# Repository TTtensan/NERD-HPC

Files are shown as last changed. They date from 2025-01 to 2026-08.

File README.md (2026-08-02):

# [NERD-HPC](https://github.com/TTtensan/NERD-HPC)

## アップデート方法
1. 本体とPCをUSBで接続する。
2. BOOTを押しながらPowerをONにする。もしくはPowerをONにした後にBOOTを押しながらRESETボタンを押す。
3. パソコンにRPI-RP2として認識されるのでsoftware/build/src/NERD_HPC.uf2をドラッグ&ドロップする。

## ファームウェアのビルド方法
どちらの方法でも、ビルド成果物は`software/build/src/NERD_HPC.uf2`に出力されます。

### コマンドラインでビルドする場合
```
(Ubuntu Desktop 24.04.1 LTS)
sudo apt install cmake python3 build-essential gcc-arm-none-eabi libnewlib-arm-none-eabi libstdc++-arm-none-eabi-newlib
```
```
git clone --recursive https://github.com/TTtensan/NERD-HPC.git
cd NERD-HPC/software
cmake -B build
cd build
make
```
この方法では、リポジトリに同梱されている`software/libraries/pico-sdk`(サブモジュール)を使ってビルドします。`--recursive`を忘れずに。

### VS Codeでビルドする場合
[Raspberry Pi Pico拡張機能](https://marketplace.visualstudio.com/items?itemName=raspberry-pi.raspberry-pi-pico)を使います。

1. リポジトリをクローンし、`software`フォルダをVS Codeで開く。
2. 推奨拡張機能のインストールを促されるので、インストールする(`.vscode/extensions.json`に定義しています)。
3. Pico拡張機能が必要なツールチェーンを`~/.pico-sdk`以下に自動でダウンロードします。使用するバージョンは`software/CMakeLists.txt`の先頭で指定しています(Pico SDK 2.2.0 / GCC 14_2_Rel1 / picotool 2.2.0-a4)。
4. サイドバーのPicoアイコンから`Compile Project`を実行する。

`.vscode`以下の設定はリポジトリで共有しています。パスはすべて`${userHome}`などの変数で書いてあるため、Windows・macOS・Linuxのいずれでもそのまま動作します。

なお、この方法ではコマンドラインの場合と違い、同梱のサブモジュールではなく`~/.pico-sdk`にダウンロードされたSDKが使われます。

## その他リンク
- 本家豊四季タイニーBASIC(Arduino版)。素晴らしいプログラムをオープンソースライセンスで公開いただいていること、大変感謝しています。製作者様に本オープンソースプロジェクトについて連絡済みです。GPLのバージョンはGPLv3とのこと。<br>[ttbasic\_arduino](https://github.com/vintagechips/ttbasic_arduino)

- CHR、2進数、16進数の処理はこちらを参考にしました。大変参考になりました。<br>[ttbasic\_arduino\_stm32](https://github.com/Tamakichi/ttbasic_arduino_stm32)

- フォントデータ。こちらをベースに一部変更しています。これによって少ないデータでフォントデータを実装することができました。ありがとうございます。<br>[ＡＱＭ１２４８Ａ グラフィックＬＣＤ (for Arduino)](https://hatakekara.com/aqm1248a/)

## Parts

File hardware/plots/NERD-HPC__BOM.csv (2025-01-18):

Reference | Value | Datasheet | Footprint | Qty | DNP
BT1,BT2,BT3,BT4 | Battery_Cell | https://akizukidenshi.com/catalog/g/g102670/ | Battery:BatteryHolder_Keystone_2466_1xAAA | 4
C1,C2,C3,C5,C7,C8,C9,C10,C11,C12,C14,C17,C19,C20,C31 | 0.1uF | https://akizukidenshi.com/catalog/g/g113374/ | Capacitor_SMD:C_0603_1608Metric | 15
C4,C15,C21,C22,C23,C24,C25,C26,C27,C28,C29 | 1uF | https://akizukidenshi.com/catalog/g/g114526/ | Capacitor_SMD:C_0603_1608Metric | 11
C6 | 10uF | https://akizukidenshi.com/catalog/g/g113161/ | Capacitor_SMD:C_0603_1608Metric | 1
C13 | 0.47uF | https://akizukidenshi.com/catalog/g/g114554/ | Capacitor_SMD:C_0603_1608Metric | 1
C16,C18 | 2.2uF | https://akizukidenshi.com/catalog/g/g116077/ | Capacitor_SMD:C_0603_1608Metric | 2
C30 | 100uF | https://akizukidenshi.com/catalog/g/g115633/ | Capacitor_SMD:C_1206_3216Metric | 1
D1,D2,D3,D5,D6,D7,D8,D9,D10,D11,D12,D13,D14 | D_Schottky | https://akizukidenshi.com/catalog/g/g111231/ | LocalFootprintLibrary:CUS01 | 13
D4 | LED | https://akizukidenshi.com/catalog/g/g104313/ | LED_THT:LED_D3.0mm | 1
J1 | USB_C_Receptacle | https://akizukidenshi.com/catalog/g/g114356/ | Connector_USB:USB_C_Receptacle_XKB_U262-16XN-4BVC11 | 1
J2 | Micro_SD_Card_Det_Hirose_DM3AT | https://akizukidenshi.com/catalog/g/g102395/ | Connector_Card:microSD_HC_Hirose_DM3AT-SF-PEJM5 | 1
J3,J4 | Conn_01x06_Socket | https://akizukidenshi.com/catalog/g/g103784/ | Connector_PinSocket_2.54mm:PinSocket_1x06_P2.54mm_Vertical | 2
LS1 | Speaker | https://akizukidenshi.com/catalog/g/g106707/ | LocalFootprintLibrary:UM1515IA085008 | 1
Q1 | Q_PMOS_GSD | https://akizukidenshi.com/catalog/g/g102553/ | Package_TO_SOT_SMD:SOT-23 | 1
Q2 | Q_NMOS_GSD | https://akizukidenshi.com/catalog/g/g106049/ | Package_TO_SOT_SMD:SOT-23 | 1
R1,R6,R7,R8,R10,R11,R12,R13 | 10k | https://akizukidenshi.com/catalog/g/g115029/ | Resistor_SMD:R_0603_1608Metric | 8
R2,R3,R9 | 27 | free | Resistor_SMD:R_0603_1608Metric | 3
R4,R5,R14,R15,R16,R17 | 5.1k | https://www.sengoku.co.jp/mod/sgk_cart/detail.php?code=EEHD-57GS | Resistor_SMD:R_0603_1608Metric | 6
R18 | 200 | free | Resistor_SMD:R_0603_1608Metric | 1
RV1,RV2 | R_Potentiometer | https://akizukidenshi.com/catalog/g/g106099/ | LocalFootprintLibrary:3386K-EY5-101TR | 2
SW1,SW2,SW6,SW7,SW8,SW9,SW10,SW11,SW12,SW13,SW14,SW15,SW16,SW17,SW18,SW19,SW20,SW21,SW22,SW23,SW24,SW25,SW26,SW27,SW28,SW29,SW30,SW31,SW32,SW33,SW34,SW35,SW36,SW37,SW38,SW39,SW40,SW41,SW42,SW43,SW44,SW45,SW46,SW47,SW48,SW49,SW50,SW51,SW52,SW53,SW54,SW55,SW56,SW57,SW58,SW59,SW60,SW61,SW62,SW63,SW64,SW65,SW66,SW67,SW68,SW69,SW70 | SW_Push | https://akizukidenshi.com/catalog/g/g103648/ | Button_Switch_THT:SW_PUSH_6mm | 67
SW3,SW4,SW5 | SW_SPDT_312 | https://akizukidenshi.com/catalog/g/g112723/ | LocalFootprintLibrary:SS-12D00-G5 | 3
U1 | RP2040 | https://akizukidenshi.com/catalog/g/g117056/ | Package_DFN_QFN:QFN-56-1EP_7x7mm_P0.4mm_EP3.2x3.2mm | 1
U2 | NJM2845DL1-33 | https://akizukidenshi.com/catalog/g/g111299/ | Package_TO_SOT_SMD:TO-252-3_TabPin2 | 1
U3 | W25Q32JVSS | https://akizukidenshi.com/catalog/g/g117346/ | Package_SON:Winbond_USON-8-1EP_3x2mm_P0.5mm_EP0.2x1.6mm | 1
U4 | MCP23017_SP | https://akizukidenshi.com/catalog/g/g109486/ | Package_DIP:DIP-28_W7.62mm | 1
U5 | AQM1248A | https://akizukidenshi.com/catalog/g/g110048/ | LocalFootprintLibrary:AQM1248A | 1
U6 | OSRB38C9AA | https://akizukidenshi.com/catalog/g/g104659/ | LocalFootprintLibrary:OSRB38C9AA | 1
X1 | SIT2001B | https://akizukidenshi.com/catalog/g/g111093/ | Package_TO_SOT_SMD:SOT-23-5 | 1

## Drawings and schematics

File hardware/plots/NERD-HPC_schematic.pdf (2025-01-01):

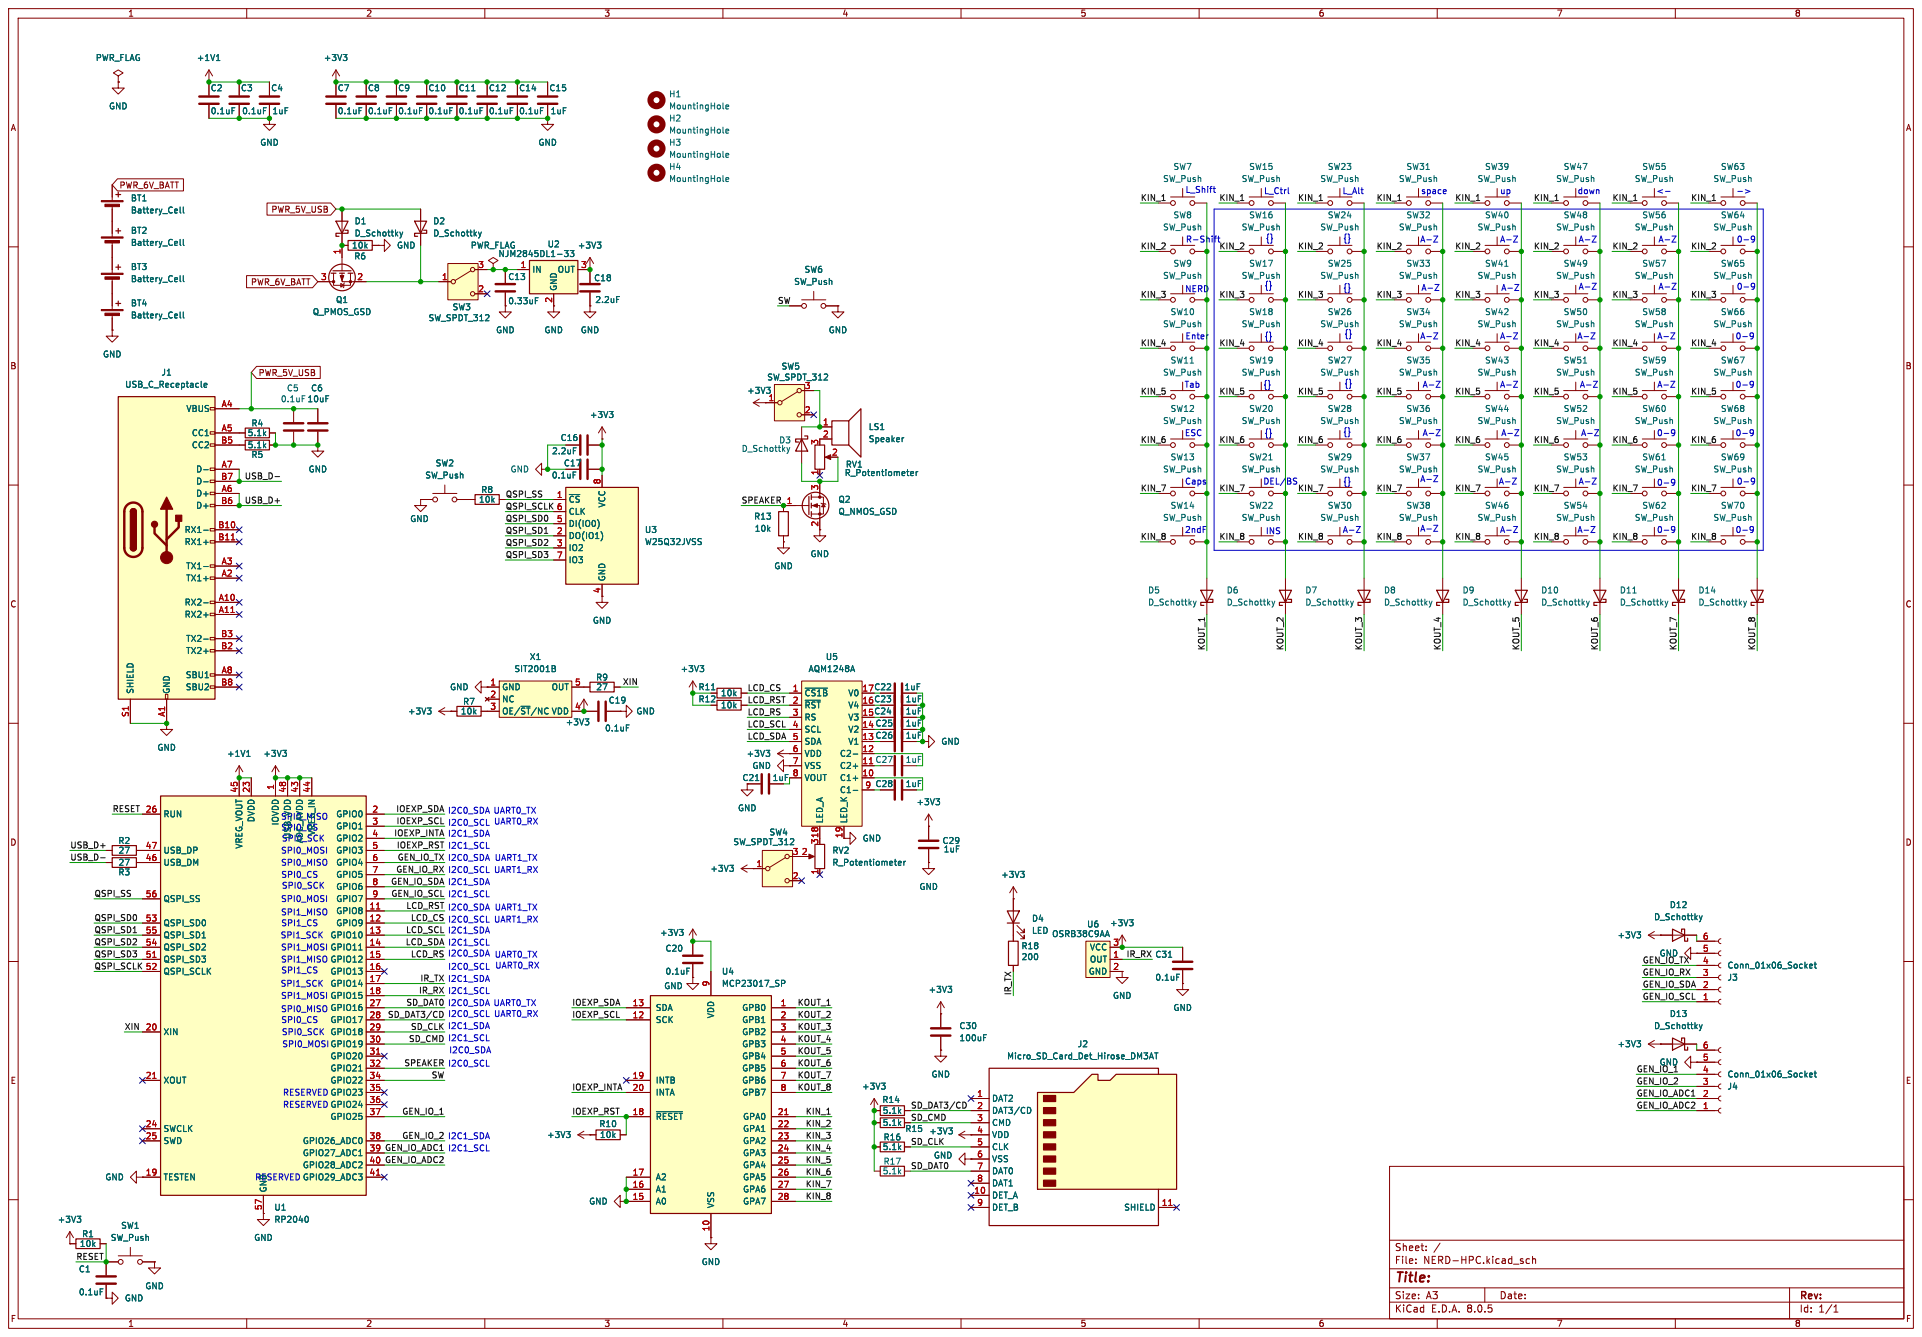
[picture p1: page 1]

H2 MountingHole H4 MountingHole H1 MountingHole H3 MountingHole C11

1 GPIO8 11 GPIO9 12 GPIO10 13 GPIO11 14 GPIO12 15 GPIO13 16 GPIO14 17 GPIO15 18 TESTEN 19 GPIO0 2 XIN 20 XOUT 21 DVDD 23 SWCLK 24 SWD 25 RUN 26 GPIO16 27 GPIO17 28 GPIO18 29 GPIO1 3 GPIO19 30 GPIO20 31 GPIO21 32 GPIO22 34 GPIO23 35 GPIO24 36 GPIO25 37 GPIO26_ADC0 38 GPIO27_ADC1 39 GPIO2 4 GPIO28_ADC2 40 GPIO29_ADC3 41 ADC_AVDD 43 VREG_IN 44 VREG_VOUT 45 USB_DM 46 USB_DP 47 USB_VDD 48 GPIO3 5 QSPI_SD3 51 QSPI_SCLK 52 QSPI_SD0 53 QSPI_SD2 54 QSPI_SD1 55 QSPI_SS 56 GND 57 GPIO4 6 GPIO5 7 GPIO6 8 GPIO7 9 +3V3 U4 MCP23017_SP GPB0 1 VSS 10 SCK 12 SDA 13 A0 15 A1 16 A2 17 ~{RESET} 18

1 GPIO8 11 GPIO9 12 GPIO10 13 GPIO11 14 GPIO12 15 GPIO13 16 GPIO14 17 GPIO15 18 TESTEN 19 GPIO0 2 XIN 20 XOUT 21 DVDD 23 SWCLK 24 SWD 25 RUN 26 GPIO16 27 GPIO17 28 GPIO18 29 GPIO1 3 GPIO19 30 GPIO20 31 GPIO21 32 GPIO22 34 GPIO23 35 GPIO24 36 GPIO25 37 GPIO26_ADC0 38 GPIO27_ADC1 39 GPIO2 4 GPIO28_ADC2 40 GPIO29_ADC3 41 ADC_AVDD 43 VREG_IN 44 VREG_VOUT 45 USB_DM 46 USB_DP 47 USB_VDD 48 GPIO3 5 QSPI_SD3 51 QSPI_SCLK 52 QSPI_SD0 53 QSPI_SD2 54 QSPI_SD1 55 QSPI_SS 56 GND 57 GPIO4 6 GPIO5 7 GPIO6 8 GPIO7 9 U1 RP2040

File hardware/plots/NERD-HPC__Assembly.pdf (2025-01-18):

1 | 2 | 3 | 4 | 5 | 6

A

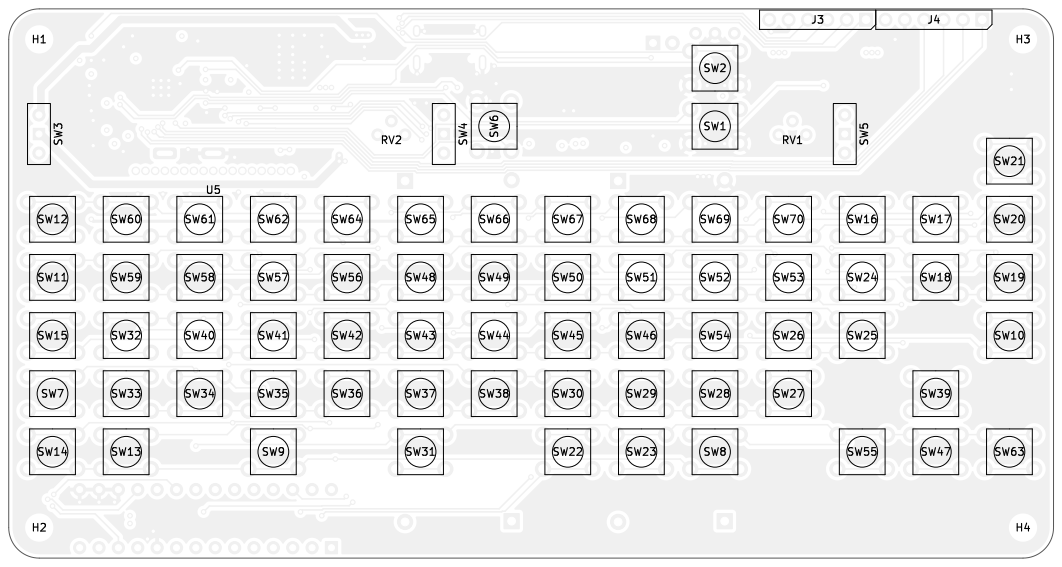
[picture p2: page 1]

1 | 2 | 3 | 4 | 5 | 6

A

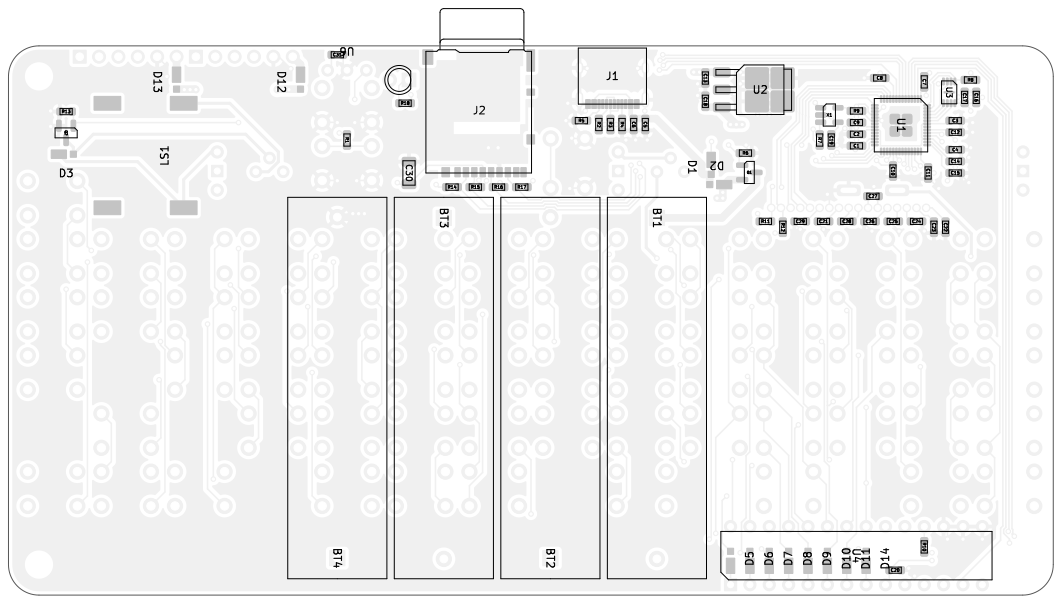
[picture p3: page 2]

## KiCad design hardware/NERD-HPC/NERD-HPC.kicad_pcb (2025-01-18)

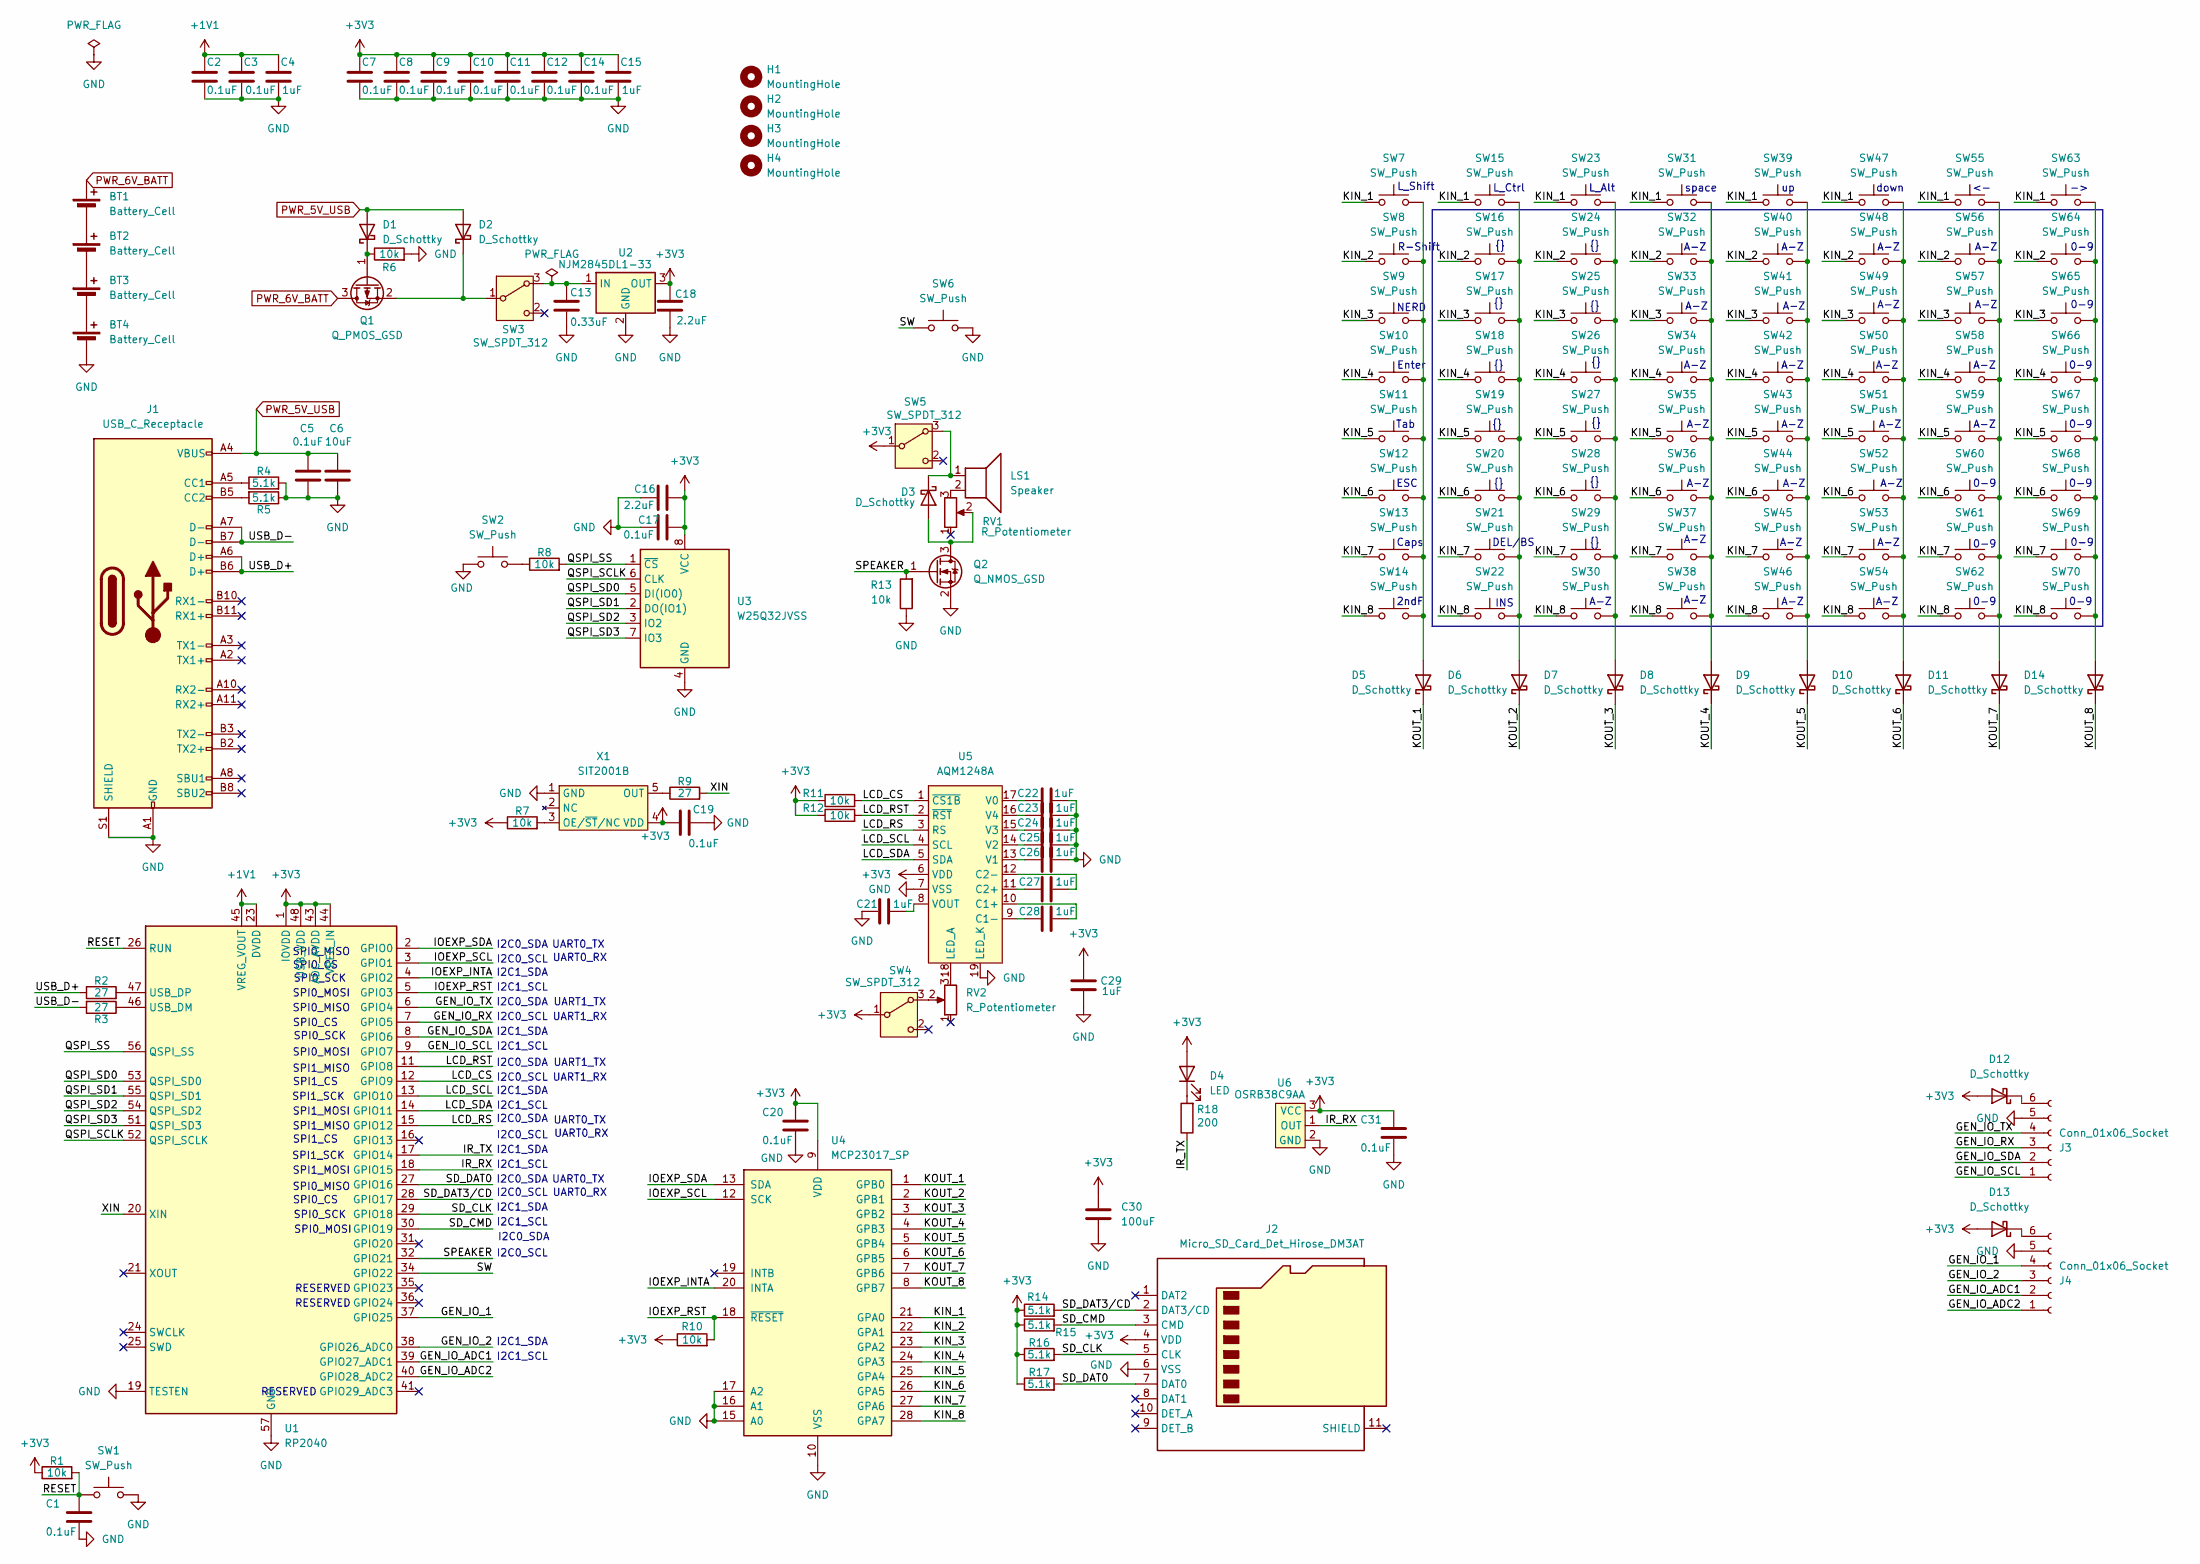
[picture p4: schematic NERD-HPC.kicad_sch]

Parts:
BT1, BT2, BT3, BT4: Battery_Cell; BatteryHolder_Keystone_2466_1xAAA
C1, C2, C3, C5, C7, C8, C9, C10, C11, C12, C14, C17, C19, C20, C31: 0.1uF; C_0603_1608Metric
C4, C15, C21, C22, C23, C24, C25, C26, C27, C28, C29: 1uF; C_0603_1608Metric
C6: 10uF; C_0603_1608Metric
C13: 0.33uF; C_0603_1608Metric
C16, C18: 2.2uF; C_0603_1608Metric
C30: 100uF; C_1206_3216Metric
D1, D2, D3, D5, D6, D7, D8, D9, D10, D11, D12, D13, D14: D_Schottky; CUS01
D4: LED; LED_D3.0mm
H1, H2, H3, H4: MountingHole; MountingHole_3.2mm_M3
J1: USB_C_Receptacle; USB_C_Receptacle_XKB_U262-16XN-4BVC11
J2: Micro_SD_Card_Det_Hirose_DM3AT; microSD_HC_Hirose_DM3AT-SF-PEJM5
J3, J4: Conn_01x06_Socket; PinSocket_1x06_P2.54mm_Vertical
LS1: Speaker; UM1515IA085008
Q1: Q_PMOS_GSD; SOT-23
Q2: Q_NMOS_GSD; SOT-23
R1, R6, R7, R8, R10, R11, R12, R13: 10k; R_0603_1608Metric
R2, R3, R9: 27; R_0603_1608Metric
R4, R5, R14, R15, R16, R17: 5.1k; R_0603_1608Metric
R18: 200; R_0603_1608Metric
RV1, RV2: R_Potentiometer; 3386K-EY5-101TR
SW1, SW2, SW6, SW7, SW8, SW9, SW10, SW11, SW12, SW13, SW14, SW15, SW16, SW17, SW18, SW19, SW20, SW21, SW22, SW23, SW24, SW25, SW26, SW27, SW28, SW29, SW30, SW31, SW32, SW33, SW34, SW35, SW36, SW37, SW38, SW39, SW40, SW41, SW42, SW43, SW44, SW45, SW46, SW47, SW48, SW49, SW50, SW51, SW52, SW53, SW54, SW55, SW56, SW57, SW58, SW59, SW60, SW61, SW62, SW63, SW64, SW65, SW66, SW67, SW68, SW69, SW70: SW_Push; SW_PUSH_6mm
SW3, SW4, SW5: SW_SPDT_312; SS-12D00-G5
U1: RP2040; QFN-56-1EP_7x7mm_P0.4mm_EP3.2x3.2mm
U2: NJM2845DL1-33; TO-252-3_TabPin2
U3: W25Q32JVSS; Winbond_USON-8-1EP_3x2mm_P0.5mm_EP0.2x1.6mm
U4: MCP23017_SP; DIP-28_W7.62mm
U5: AQM1248A
U6: OSRB38C9AA
X1: SIT2001B; SOT-23-5

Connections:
+1V1: C2.1, C3.1, C4.1, U1.23 (DVDD), U1.45 (VREG_VOUT), U1.50 (DVDD)
+3V3: C7.1, C8.1, C9.1, C10.1, C11.1, C12.1, C14.1, C15.1, C16.2, C17.1, C18.1, C19.2, C20.1, C29.1, C30.1, C31.1, D4.2 (A), D12.2 (A), D13.2 (A), J2.4 (VDD), R1.1, R7.1, R10.1, R11.1, R12.1, R14.1, R15.1, R16.1, R17.1, SW4.1 (B), SW5.1 (B), U1.1 (IOVDD), U1.10 (IOVDD), U1.22 (IOVDD), U1.33 (IOVDD), U1.42 (IOVDD), U1.43 (ADC_AVDD), U1.44 (VREG_IN), U1.48 (USB_VDD), U1.49 (IOVDD), U2.3 (OUT), U3.8 (VCC), U4.9 (VDD), U5.6 (VDD), U6.3 (VCC), X1.4 (VDD)
/GEN_IO_1: J4.4, U1.37 (GPIO25)
/GEN_IO_2: J4.3, U1.38 (GPIO26_ADC0)
/GEN_IO_ADC1: J4.2, U1.39 (GPIO27_ADC1)
/GEN_IO_ADC2: J4.1, U1.40 (GPIO28_ADC2)
/GEN_IO_RX: J3.3, U1.7 (GPIO5)
/GEN_IO_SCL: J3.1, U1.9 (GPIO7)
/GEN_IO_SDA: J3.2, U1.8 (GPIO6)
/GEN_IO_TX: J3.4, U1.6 (GPIO4)
/IOEXP_INTA: U1.4 (GPIO2), U4.20 (INTA)
/IOEXP_RST: R10.2, U1.5 (GPIO3), U4.18 (~RESET)
/IOEXP_SCL: U1.3 (GPIO1), U4.12 (SCK)
/IOEXP_SDA: U1.2 (GPIO0), U4.13 (SDA)
/IR_RX: U1.18 (GPIO15), U6.1 (OUT)
/IR_TX: R18.1, U1.17 (GPIO14)
/KIN_1: SW7.1, SW15.1, SW23.1, SW31.1, SW39.1, SW47.1, SW55.1, SW63.1, U4.21 (GPA0)
/KIN_2: SW8.1, SW16.1, SW24.1, SW32.1, SW40.1, SW48.1, SW56.1, SW64.1, U4.22 (GPA1)
/KIN_3: SW9.1, SW17.1, SW25.1, SW33.1, SW41.1, SW49.1, SW57.1, SW65.1, U4.23 (GPA2)
/KIN_4: SW10.1, SW18.1, SW26.1, SW34.1, SW42.1, SW50.1, SW58.1, SW66.1, U4.24 (GPA3)
/KIN_5: SW11.1, SW19.1, SW27.1, SW35.1, SW43.1, SW51.1, SW59.1, SW67.1, U4.25 (GPA4)
/KIN_6: SW12.1, SW20.1, SW28.1, SW36.1, SW44.1, SW52.1, SW60.1, SW68.1, U4.26 (GPA5)
/KIN_7: SW13.1, SW21.1, SW29.1, SW37.1, SW45.1, SW53.1, SW61.1, SW69.1, U4.27 (GPA6)
/KIN_8: SW14.1, SW22.1, SW30.1, SW38.1, SW46.1, SW54.1, SW62.1, SW70.1, U4.28 (GPA7)
/KOUT_1: D5.1 (K), U4.1 (GPB0)
/KOUT_2: D6.1 (K), U4.2 (GPB1)
/KOUT_3: D7.1 (K), U4.3 (GPB2)
/KOUT_4: D8.1 (K), U4.4 (GPB3)
/KOUT_5: D9.1 (K), U4.5 (GPB4)
/KOUT_6: D10.1 (K), U4.6 (GPB5)
/KOUT_7: D11.1 (K), U4.7 (GPB6)
/KOUT_8: D14.1 (K), U4.8 (GPB7)
/LCD_CS: R11.2, U1.12 (GPIO9), U5.1 (~CS1B)
/LCD_RS: U1.15 (GPIO12), U5.3 (RS)
/LCD_RST: R12.2, U1.11 (GPIO8), U5.2 (~RST)
/LCD_SCL: U1.13 (GPIO10), U5.4 (SCL)
/LCD_SDA: U1.14 (GPIO11), U5.5 (SDA)
/QSPI_SCLK: U1.52 (QSPI_SCLK), U3.6 (CLK)
/QSPI_SD0: U1.53 (QSPI_SD0), U3.5 (DI(IO0))
/QSPI_SD1: U1.55 (QSPI_SD1), U3.2 (DO(IO1))
/QSPI_SD2: U1.54 (QSPI_SD2), U3.3 (IO2)
/QSPI_SD3: U1.51 (QSPI_SD3), U3.7 (IO3)
/QSPI_SS: R8.2, U1.56 (QSPI_SS), U3.1 (~CS)
/RESET: C1.1, R1.2, SW1.1, U1.26 (RUN)
/SD_CLK: J2.5 (CLK), R16.2, U1.29 (GPIO18)
/SD_CMD: J2.3 (CMD), R15.2, U1.30 (GPIO19)
/SD_DAT0: J2.7 (DAT0), R17.2, U1.27 (GPIO16)
/SD_DAT3/CD: J2.2 (DAT3/CD), R14.2, U1.28 (GPIO17)
/SPEAKER: Q2.1 (G), R13.2, U1.32 (GPIO21)
/SW: SW6.1, U1.34 (GPIO22)
/USB_D+: J1.A6 (D+), J1.B6 (D+), R2.1
/USB_D-: J1.A7 (D-), J1.B7 (D-), R3.2
/XIN: R9.2, U1.20 (XIN)
GND: BT4.2 (-), C1.2, C2.2, C3.2, C4.2, C5.2, C6.2, C7.2, C8.2, C9.2, C10.2, C11.2, C12.2, C13.2, C14.2, C15.2, C16.1, C17.2, C18.2, C19.1, C20.2, C21.1, C22.2, C23.2, C24.2, C25.2, C26.2, C29.2, C30.2, C31.2, J1.A1 (GND), J1.A12 (GND), J1.B1 (GND), J1.B12 (GND), J1.S1 (SHIELD), J2.6 (VSS), J3.5, J4.5, Q2.2 (S), R4.2, R5.1, R6.2, R13.1, SW1.2, SW2.1, SW6.2, U1.19 (TESTEN), U1.57 (GND), U2.2 (GND), U3.4 (GND), U4.10 (VSS), U4.15 (A0), U4.16 (A1), U4.17 (A2), U5.7 (VSS), U5.19 (LED_K), U6.2 (GND), X1.1 (GND)
unnamed: BT1.2 (-), BT2.1 (+)
unnamed: BT2.2 (-), BT3.1 (+)
unnamed: BT3.2 (-), BT4.1 (+)
unnamed: D1.1 (K), Q1.1 (G), R6.1
unnamed: D2.1 (K), Q1.2 (S), SW3.1 (B)
unnamed: D3.2 (A), Q2.3 (D), RV1.2
unnamed: D3.1 (K), LS1.1, SW5.3 (A)
unnamed: D4.1 (K), R18.2
unnamed: D5.2 (A), SW7.2, SW8.2, SW9.2, SW10.2, SW11.2, SW12.2, SW13.2, SW14.2
unnamed: D6.2 (A), SW15.2, SW16.2, SW17.2, SW18.2, SW19.2, SW20.2, SW21.2, SW22.2
unnamed: D7.2 (A), SW23.2, SW24.2, SW25.2, SW26.2, SW27.2, SW28.2, SW29.2, SW30.2
unnamed: D8.2 (A), SW31.2, SW32.2, SW33.2, SW34.2, SW35.2, SW36.2, SW37.2, SW38.2
unnamed: D9.2 (A), SW39.2, SW40.2, SW41.2, SW42.2, SW43.2, SW44.2, SW45.2, SW46.2
unnamed: D10.2 (A), SW47.2, SW48.2, SW49.2, SW50.2, SW51.2, SW52.2, SW53.2, SW54.2
unnamed: D11.2 (A), SW55.2, SW56.2, SW57.2, SW58.2, SW59.2, SW60.2, SW61.2, SW62.2
unnamed: D12.1 (K), J3.6
unnamed: D13.1 (K), J4.6
unnamed: D14.2 (A), SW63.2, SW64.2, SW65.2, SW66.2, SW67.2, SW68.2, SW69.2, SW70.2
unnamed: J1.A5 (CC1), R4.1
unnamed: J1.B5 (CC2), R5.2
unnamed: LS1.2, RV1.3
unnamed: R8.1, SW2.2
unnamed: C13.1, SW3.3 (A), U2.1 (IN)
unnamed: RV2.2, SW4.3 (A)
unnamed: R3.1, U1.46 (USB_DM)
unnamed: R2.2, U1.47 (USB_DP)
unnamed: C28.2, U5.10 (C1+)
unnamed: C28.1, U5.9 (C1-)
unnamed: C27.1, U5.11 (C2+)
unnamed: C27.2, U5.12 (C2-)
unnamed: RV2.3, U5.18 (LED_A)
unnamed: C22.1, U5.17 (V0)
unnamed: C26.1, U5.13 (V1)
unnamed: C25.1, U5.14 (V2)
unnamed: C24.1, U5.15 (V3)
unnamed: C23.1, U5.16 (V4)
unnamed: C21.2, U5.8 (VOUT)
unnamed: R7.2, X1.3 (OE/~ST/NC)
unnamed: R9.1, X1.5 (OUT)
PWR_5V_USB: C5.1, C6.1, D1.2 (A), D2.2 (A), J1.A4 (VBUS), J1.A9 (VBUS), J1.B4 (VBUS), J1.B9 (VBUS)
PWR_6V_BATT: BT1.1 (+), Q1.3 (D)

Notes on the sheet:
A-Z
I2C1_SDA
I2C0_SDA
ESC
SPI1_MOSI
0-9
UART0_RX
2ndF
Tab
SPI0_SCK
I2C1_SCL
I2C0_SCL
RESERVED
DEL/BS
SPI0_CS
Caps
SPI0_MISO
SPI1_CS
UART1_RX
Enter
SPI1_SCK
R-Shift
down
UART1_TX
SPI0_MOSI
SPI1_MISO
L_Ctrl
UART0_TX
NERD
L_Alt
L_Shift
INS
space

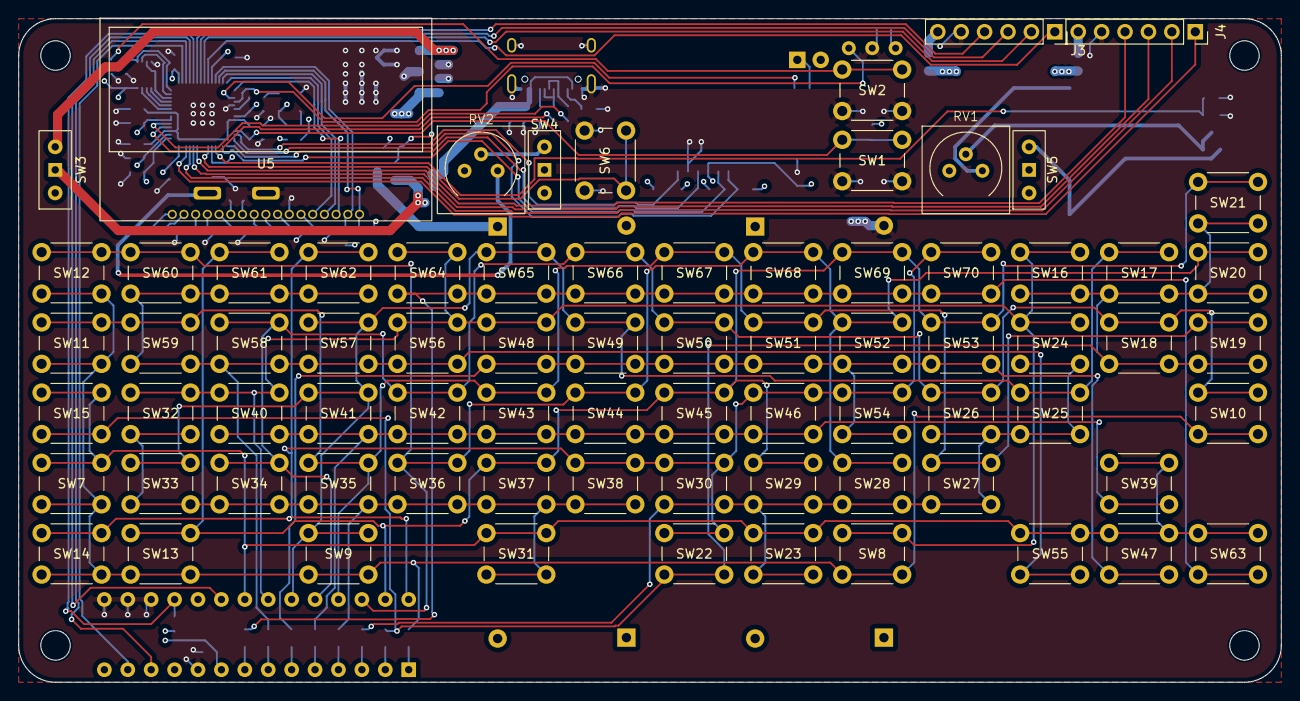
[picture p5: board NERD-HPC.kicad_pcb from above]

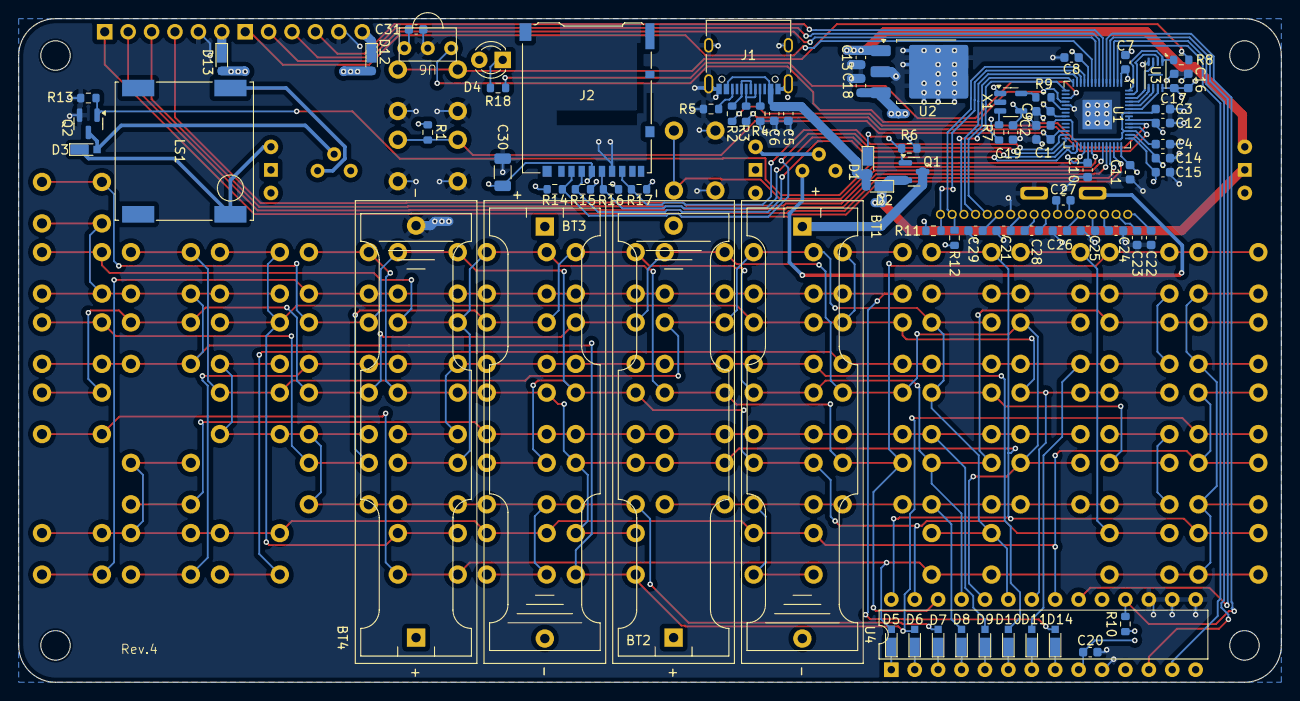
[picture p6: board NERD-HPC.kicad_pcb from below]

Board: 4 copper layers, 137.0 x 72.0 mm, 157 parts (78 on the bottom side), 95 nets.

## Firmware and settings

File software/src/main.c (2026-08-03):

#include <stdio.h>
#include "stdlib.h"
#include "pico/stdlib.h"
#include "pico/multicore.h"
#include "hardware/clocks.h"
#include "font.h"
#include "pin.h"
#include "lcd.h"
#include "speaker.h"
#include "sd.hpp"
#include "com_func.h"
#include "draw.h"
#include "io.h"
#include "ioexp.h"
#include "mcore.h"
#include "tusb.h"
#include "usb_descriptors.h"
#include "usb.h"
#include "basic.hpp"

void core1_entry() {
    while(true) {
        tud_task();
        usb_send_keycode_task();
        lcd_task(); // 画面転送。core0のBASICを止めないようこちらで回す
    }
}

int main() {

    // RP2040の水晶は12MHzで、sys_clkはそこからPLLで作られている。
    // 既定の125MHzはPLLの分周比で決まっているだけなので、
    // 基板に手を入れずにここで引き上げられる。
    // BASICの実行速度はほぼこの比で効く。
    // spi_init()/i2c_init()/PWMはclk_periから分周比を計算するので、
    // 必ずpin_init()より前に呼ぶこと
    set_sys_clock_khz(250000, true);

    stdio_init_all();
    tusb_init();

    printf("Hello, I'm NERD BOY\n");

    srand(get_seed());
    font_init();
    pin_init();
    io_init();
    ioexp_init();
    lcd_init();
    speaker_init();
    sd_init();
    mcore_init();

    multicore_launch_core1(core1_entry);

    while (true) {
        basic();
    }

}

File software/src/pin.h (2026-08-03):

#ifndef PIN_H_
#define PIN_H_

#include "hardware/i2c.h"

#define PIN_IOEXP_SDA 0
#define PIN_IOEXP_SCL 1
#define PIN_IOEXP_INTA 2
#define PIN_IOEXP_RST 3

#define PIN_GEN_IO_TX 4
#define PIN_GEN_IO_RX 5
#define PIN_GEN_IO_SDA 6
#define PIN_GEN_IO_SCL 7

#define PIN_LCD_RST 8
#define PIN_LCD_CS 9
#define PIN_LCD_SCL 10
#define PIN_LCD_SDA 11
#define PIN_LCD_RS 12

#define PIN_IR_TX 14
#define PIN_IR_RX 15

#define PIN_SD_DAT0 16
#define PIN_SD_DAT3 17
#define PIN_SD_CLK 18
#define PIN_SD_CMD 19

#define PIN_SPEAKER 21
#define PIN_SW 22

#define PIN_GEN_IO_1 25
#define PIN_GEN_IO_2 26
#define PIN_GEN_IO_3 27
#define PIN_GEN_IO_4 28

#define UART_ID_GENIO uart1
#define I2C_ID_GENIO i2c1

// 1MHz(Fast-mode Plus)は外付けプルアップが1kΩ級でないと成立しない。
// 1MHzではIOピンに指で触れただけでバスが完全無応答になり、
// MCP23017のレジスタが化けたり、キー入力が2秒ほど止まったりしていた。
// 400kHzに落とすと再現しなくなったので、こちらを採用する。
// プルアップ抵抗を1kΩ級に見直せば1MHzへ戻せる
#define I2C0_BAUDRATE 400000

void pin_init();

#endif

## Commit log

2025-01-01 add hardware file
    [NERD-HPC-B_Cu.gbl, NERD-HPC-B_Mask.gbs, NERD-HPC-B_Paste.gbp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]
2025-01-01 update bom
    [NERD-HPC.kicad_sch, NERD-HPC_CASE_B.kicad_sch, NERD-HPC_CASE_F.kicad_sch]
2025-01-01 add pico sdk
2025-01-01 use libraries/pico-sdk
2025-01-13 include dev_hid_composite sample
2025-01-13 access current_keycode
2025-01-14 fix keycode and increase list size
    [basic.cpp, ioexp.c]
2025-01-14 add keycode and fix keycode
    [ioexp.c]
2025-01-18 initial reset lcd and ioexpander
    [basic.cpp, ioexp.c, lcd.c]
2025-01-18 NERD HPC pcb Rev.4
    [NERD-HPC-B_Cu.gbl, NERD-HPC-B_Mask.gbs, NERD-HPC-B_Paste.gbp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]
2025-01-18 NERD HPC CASE F pcb Rev.4
    [NERD-HPC_CASE_F-B_Cu.gbl, NERD-HPC_CASE_F-B_Mask.gbs, NERD-HPC_CASE_F-B_Paste.gbp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]
2025-01-18 add assembly pdf
2025-01-18 add BOM file
    [NERD-HPC__BOM.csv]
2025-01-18 move plot file
    [NERD-HPC__BOM.csv]
2025-01-23 change pico sdk v1.4.0 to v2.1.0
2025-01-23 build with pico-sdk v2.1.0
2025-02-11 add GEN IO uart
2025-06-04 add i2c function
2025-06-16 fix GCLS cursor position and IOUR IOIR
    [basic.cpp, lcd.c]
2025-07-26 fix hex bin display and save
    [basic.cpp]
2025-09-22 change timer irq to pin irq
2025-09-26 change to timer interrupt and add i2c recovery process
2025-10-02 disable i2c recovery process
2026-07-21 fix: GTRI塗りつぶしで頂点位置がずれるバグを修正
    走査線塗りつぶしのx座標を(int16_t)キャストで切り捨てていたため、
    Bresenham線描画(輪郭)の丸めと不一致となり辺が最大1pxずれていた。
    lroundfで四捨五入するよう変更し、fill=0/1で頂点位置が一致するようにした。
    [lcd.c]
2026-07-21 build: GTRI塗りつぶし修正を反映したファームウェアを再ビルド
2026-07-21 Fix vertex shift in lcd_triangle fill
    The scanline fill accumulated the long-edge x (sx) across both the
    upper and lower half loops. Because sx was advanced once more after the
    last upper-half row and both loops drew the shared y1 scanline, the long
    edge was sampled one row too far in the lower half, shifting vertices by
    one pixel (e.g. two adjacent GTRI triangles left a stray pixel outside
    the intended rectangle).
    Recompute each edge x directly from the vertices per scanline instead of
    accumulating. This also removes the dx12/dx23 divisions that produced
    division-by-zero (+/-inf) on flat top/bottom edges.
    [lcd.c]
2026-08-02 ビルドフォルダを_buildからbuildへ移行し、VS Codeでのビルドに対応
    VS CodeのRaspberry Pi Pico拡張機能が生成するビルドフォルダ名に合わせて
    _buildをbuildにリネームした。追跡対象のNERD_HPC.uf2の場所と.gitignoreの
    除外設定、READMEの記載を合わせて更新している。
    またPico拡張機能が生成した設定一式を追加した。.vscode以下のパスはすべて
    ${userHome}などの変数で書かれているため、Windows・macOS・Linuxのいずれでも
    そのまま動作する。READMEにはコマンドラインとVS Codeの両方の手順を記載した。
2026-08-02 バージョンを1.13.3に更新
    STR_VERSIONを1.13.2から1.13.3に変更し、ビルド済みのNERD_HPC.uf2を更新した。
2026-08-02 gitignoreのビルド成果物の指定をsoftware/.gitignoreに一本化
    software/.gitignoreのbuildがディレクトリごと除外していたため、ルート側の
    !software/build/srcの例外が効かず、NERD_HPC.uf2をgit addできなくなっていた。
    Gitはディレクトリごと除外されたパスの中身を再包含できないため、build/*に
    変更した上で例外指定を書き直した。
    あわせてルート側の重複していた指定を削除し、software配下のビルド成果物の
    管理をsoftware/.gitignoreに集約した。
2026-08-02 fix: IO Expanderのキー入力でフリーズするバグを修正
    キースキャンをrepeating_timerのコールバック(割り込みコンテキスト)から
    実行していたが、1回のスキャンでI2Cを16回叩くため、バスが不調になると
    割り込みの中でCPUを数百ms占有して端末全体が固まっていた。
    割り込みを廃止し、メインループから呼ぶioexp_task()方式に変更。
    またIOピンに外部から触れると復帰不能になる問題が2経路あったため、
    自動復旧を実装した。
    スキャン方式の変更:
    - I2Cのタイムアウトを30ms->2msに短縮(I2C0は1MHzなので3バイトでも30us程度)
    - 通信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
    [basic.cpp, ioexp.c]
2026-08-02 build: IO Expanderのフリーズ修正を反映したファームウェアを再ビルド
2026-08-02 fix: I2Cタイムアウト短縮によるIODIRAの化けと、バス固着時のフリーズを修正
    前コミットで IOEXP_I2C_TIMEOUT_US を 30ms から 2ms に縮めたのが原因で、
    NERD IDE からの転送が途中で止まり、BASICのGETKEYが押していないキーを
    返すようになっていた。実機のレジスタダンプで原因を特定した。
    転送が途中で打ち切られるとTX FIFOに積んだバイトが後から流れ出て
    バイト列が1つずれる。MCP23017は逐次モード(SEQOP=0)でアドレスが
    自動インクリメントするため、「レジスタアドレス+データ」の組が
    ずれて解釈され、IODIRAに隣のレジスタ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
    [ioexp.c]
2026-08-02 build: IODIRAの化けとバス固着の修正を反映したファームウェアを再ビルド
2026-08-02 fix: I2C0を400kHzに変更し、IOピンに触れたときのバス固着を解消
    1MHz(Fast-mode Plus)は外付けプルアップが1kΩ級でないと成立しない。
    実機ではIOピンに指で触れただけでI2Cバスが完全無応答になり、
    MCP23017のレジスタが化けたり、キー入力が2秒ほど止まったりしていた。
    400kHzに落として検証したところ、同じ操作で bus-dead / config-lost の
    どちらも発生しなくなったため、こちらを採用する。
    プルアップ抵抗を1kΩ級に見直せば1MHzへ戻せる。
    速度への影響:
    - 通常のBASIC実行中は省略経路により1スキャン3トランザクション。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
    [pin.h]
2026-08-02 build: I2C0の400kHz化を反映したファームウェアを再ビルド
2026-08-03 バージョン表記をv1.13.4に変更
2026-08-03 perf: BASIC実行時のボトルネックを3点解消
    LCDの全画面転送、シリアル出力、行ポインタの探索がそれぞれ
    BASICの実行速度を落としていたため、以下を修正した。
    - lcd_disp_vbuf()の1バイトずつのSPI転送をページ単位の一括転送に変更。
    60Hzのタイマ割り込みから1027回/フレーム呼ばれていたものが16回になる
    - putch2()の1文字ごとのprintf()をやめ、64バイトのバッファに溜めて
    改行かバッファ満杯でまとめて書き出すようにした。
    入力待ちに入る前(getch2)にフラッシュする
    - getlp()に行番号→行ポインタの直接マップキャッシ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
    [basic.cpp, lcd.c]
2026-08-03 build: 実行速度の改善を反映したファームウェアを再ビルド
2026-08-03 perf: sys_clkの引き上げと画面転送のcore1移行でBASICを高速化
    BASIC実行時のボトルネックのうち、インタプリタの外にあるものを解消する。
    - sys_clkを125MHzから250MHzへ引き上げる。RP2040の水晶は12MHzで、
    125MHzはPLLの逓倍結果でしかないため、基板に手を入れずに変更できる。
    フラッシュのSCKが定格ぎりぎりの125MHzになるのを避けるため、
    PICO_FLASH_SPI_CLKDIVを4にして62.5MHzへ落とす。
    - 画面転送をcore0のrepeating_timerからcore1のメインループへ移す。
    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
2026-08-03 build: 処理速度の改善を反映したファームウェアを再ビルド
2026-08-03 バージョン表記をv1.13.5に変更
2026-08-08 fix: メモリ破壊につながる不具合と境界チェック漏れを修正
    - sd: f_read()に未初期化ポインタを渡していたのを実体の変数に修正
    - sd: BMPヘッダのリトルエンディアン合成のシフト量を24/16/8に修正
    - sd: bmp/nbi/nbmの幅・高さを48x128バッファに収まるよう頭打ちに
    - sd: sd_get_by_num()/spi_get_by_num()の範囲チェックのoff-by-oneを修正
    - ir: ir_copy()で配列の空きが尽きたら打ち切るように(以前は書き続けていた)
    - com_func: get_seed()のseedを0で初期化
    - io: 未対応のIO番号でGPIO0を操作してしまうのを防止
    - speaker: freq=0のゼロ除算と、低い周波数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
    [io.c, ir.c, sd.cpp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]
2026-08-08 バージョン表記をv1.13.6に変更
2026-08-08 build: 不具合修正を反映したファームウェアを再ビルド
2026-08-24 fix: SETFの後に「;」で文を繋げるとSyntax errorになる不具合を修正
    isetf()が文字列の直後をI_EOLのみ文末として扱っていたため、
    文の区切りであるI_SEMIで無条件にSyntax errorになっていた。
    PRINT等と同様にI_SEMIも文末として許容する（I_SEMIは消費せず、
    メインループ側で読み飛ばさせる）。
    あわせて、カンマを無検査でスキップしていた箇所にI_COMMAの
    チェックを追加した。
    [basic.cpp]
2026-08-24 build: SETFの不具合修正を反映したファームウェアを再ビルド
2026-08-24 fix: ESCでプログラムを中断した際に音を止めるよう修正
    PLYSNDで鳴らしている最中にESCで中断すると、音が鳴りっぱなしに
    なっていた。中断を検出した箇所でSTPSNDと同じstop_sound()を呼ぶ。
    istpsnd()に合わせて_SPEAKER_でガードしている。
    [basic.cpp]
2026-08-24 build: ESC中断時の消音対応を反映したファームウェアを再ビルド
2026-09-11 build: バージョンを1.13.7に更新してファームウェアを再ビルド
